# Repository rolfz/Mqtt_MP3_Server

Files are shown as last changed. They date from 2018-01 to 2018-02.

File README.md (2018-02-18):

# Mqtt MP3 Player based on Wemos-D1 ESP8266 circuit and VS1053 audio module

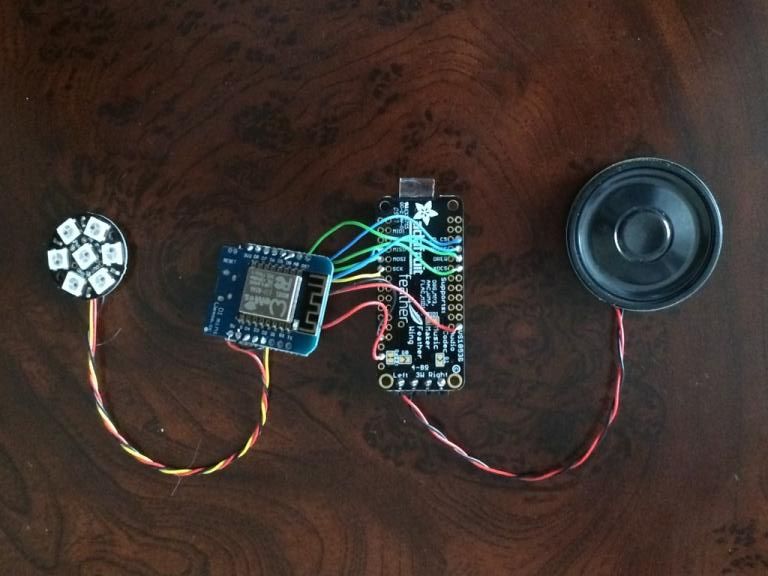
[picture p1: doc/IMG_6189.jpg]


## Functionality:

	This module was created to be controlled by Node-Red over a MQTT Broker.
	The module understands various tags such as:
			 /Zaudio/play  "file to play with extension" 8.3 format
			 /Zaudio/volume xxx (volume in db) 0 to 100db is possible
			 /Zaudio/command stop (will stop the file played)
			
	The module also allows to connect a Neoled display module with 7 leds
			 /Zaudio/neoled #xxyyzz  (set color in hex rgb format

## Hardware:
	Wemos D1 module, SPI bus used to communicate with audio module
	
	Adafruit VS1053 module with 3W amplifier PRODUCT ID: 3436
	
	Micro SD card 128mB our larger FAT format.
	
	Connections:
			Wemos D1		-      VS1053   -   Neoled
			D8						MISO
			D7						MOSI
			D5						SCK
			D4						SD-CS
			D6						MP3-CS
			D3						DREQ
			DO						XDCS
			D2									IN
			+5V						AUDIO +5V	5V
			+3V						DIGIT.+3V
	
	! Use min. 5V 2Amp USB to supply both circuits + LED's
		
## Software Libraries:

	Adafruit_Neopixel
	Adafruit_VS1053_Library-master
	pubsubclient (MQTT library)
	
## Software Main file:
	mqtt_mp3_server.ino contains all customized code based on the MQTT client example
	wifi_settings.h 	contains the WIFI private setting

## Using the Zaudio module with Node-red
	Zaudio was tested with a connection to an MQTT brocker running on a RPI3 board
		Software installed was Openhabian with MQTT and Node-red modules installed.
		
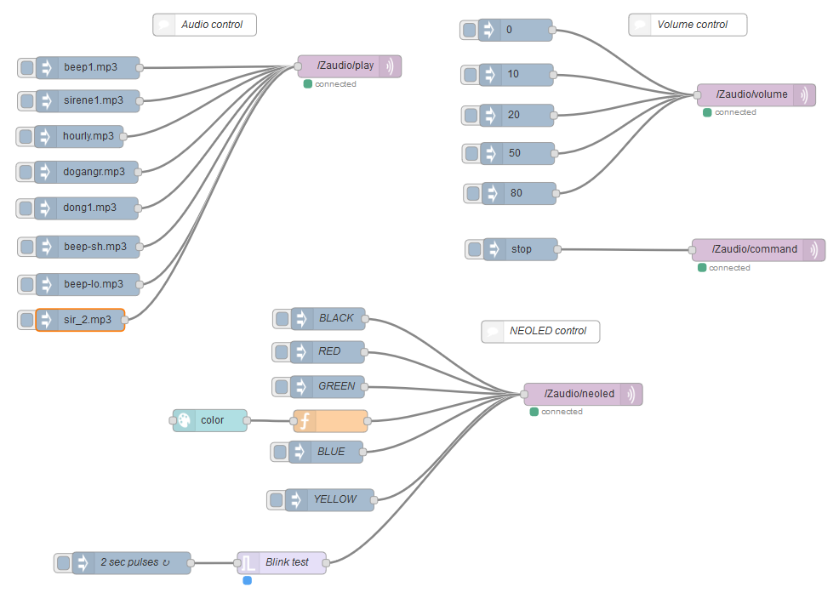
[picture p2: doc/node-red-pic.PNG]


	v1.1 rz 21.2.2018	added OTA code
	v1.0 rz 28.1.2018   orginial code

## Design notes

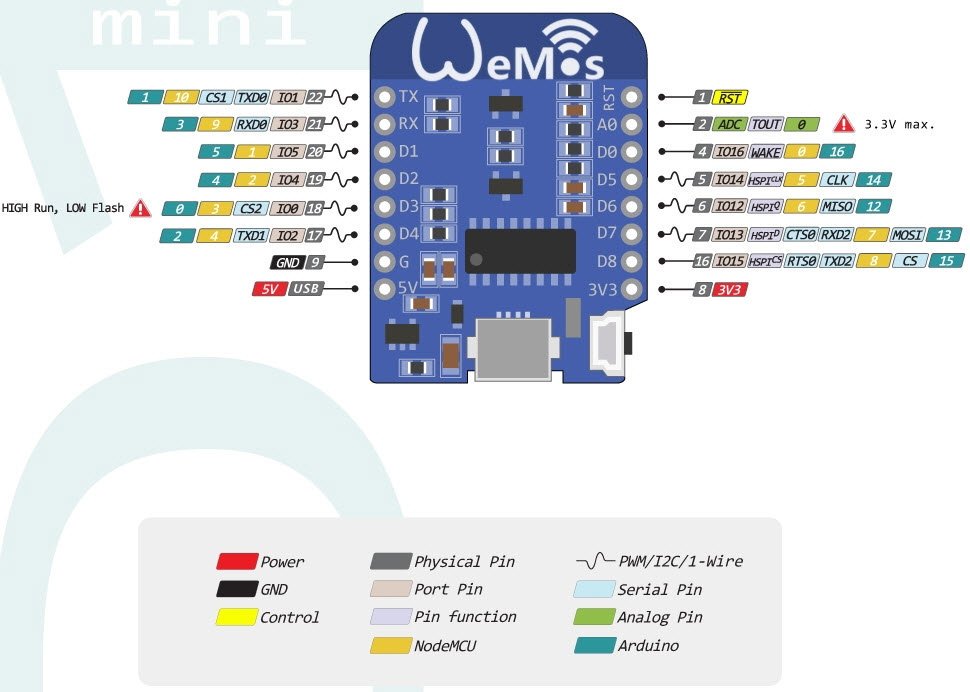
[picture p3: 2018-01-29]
doc/wemos d1 pinout.jpg

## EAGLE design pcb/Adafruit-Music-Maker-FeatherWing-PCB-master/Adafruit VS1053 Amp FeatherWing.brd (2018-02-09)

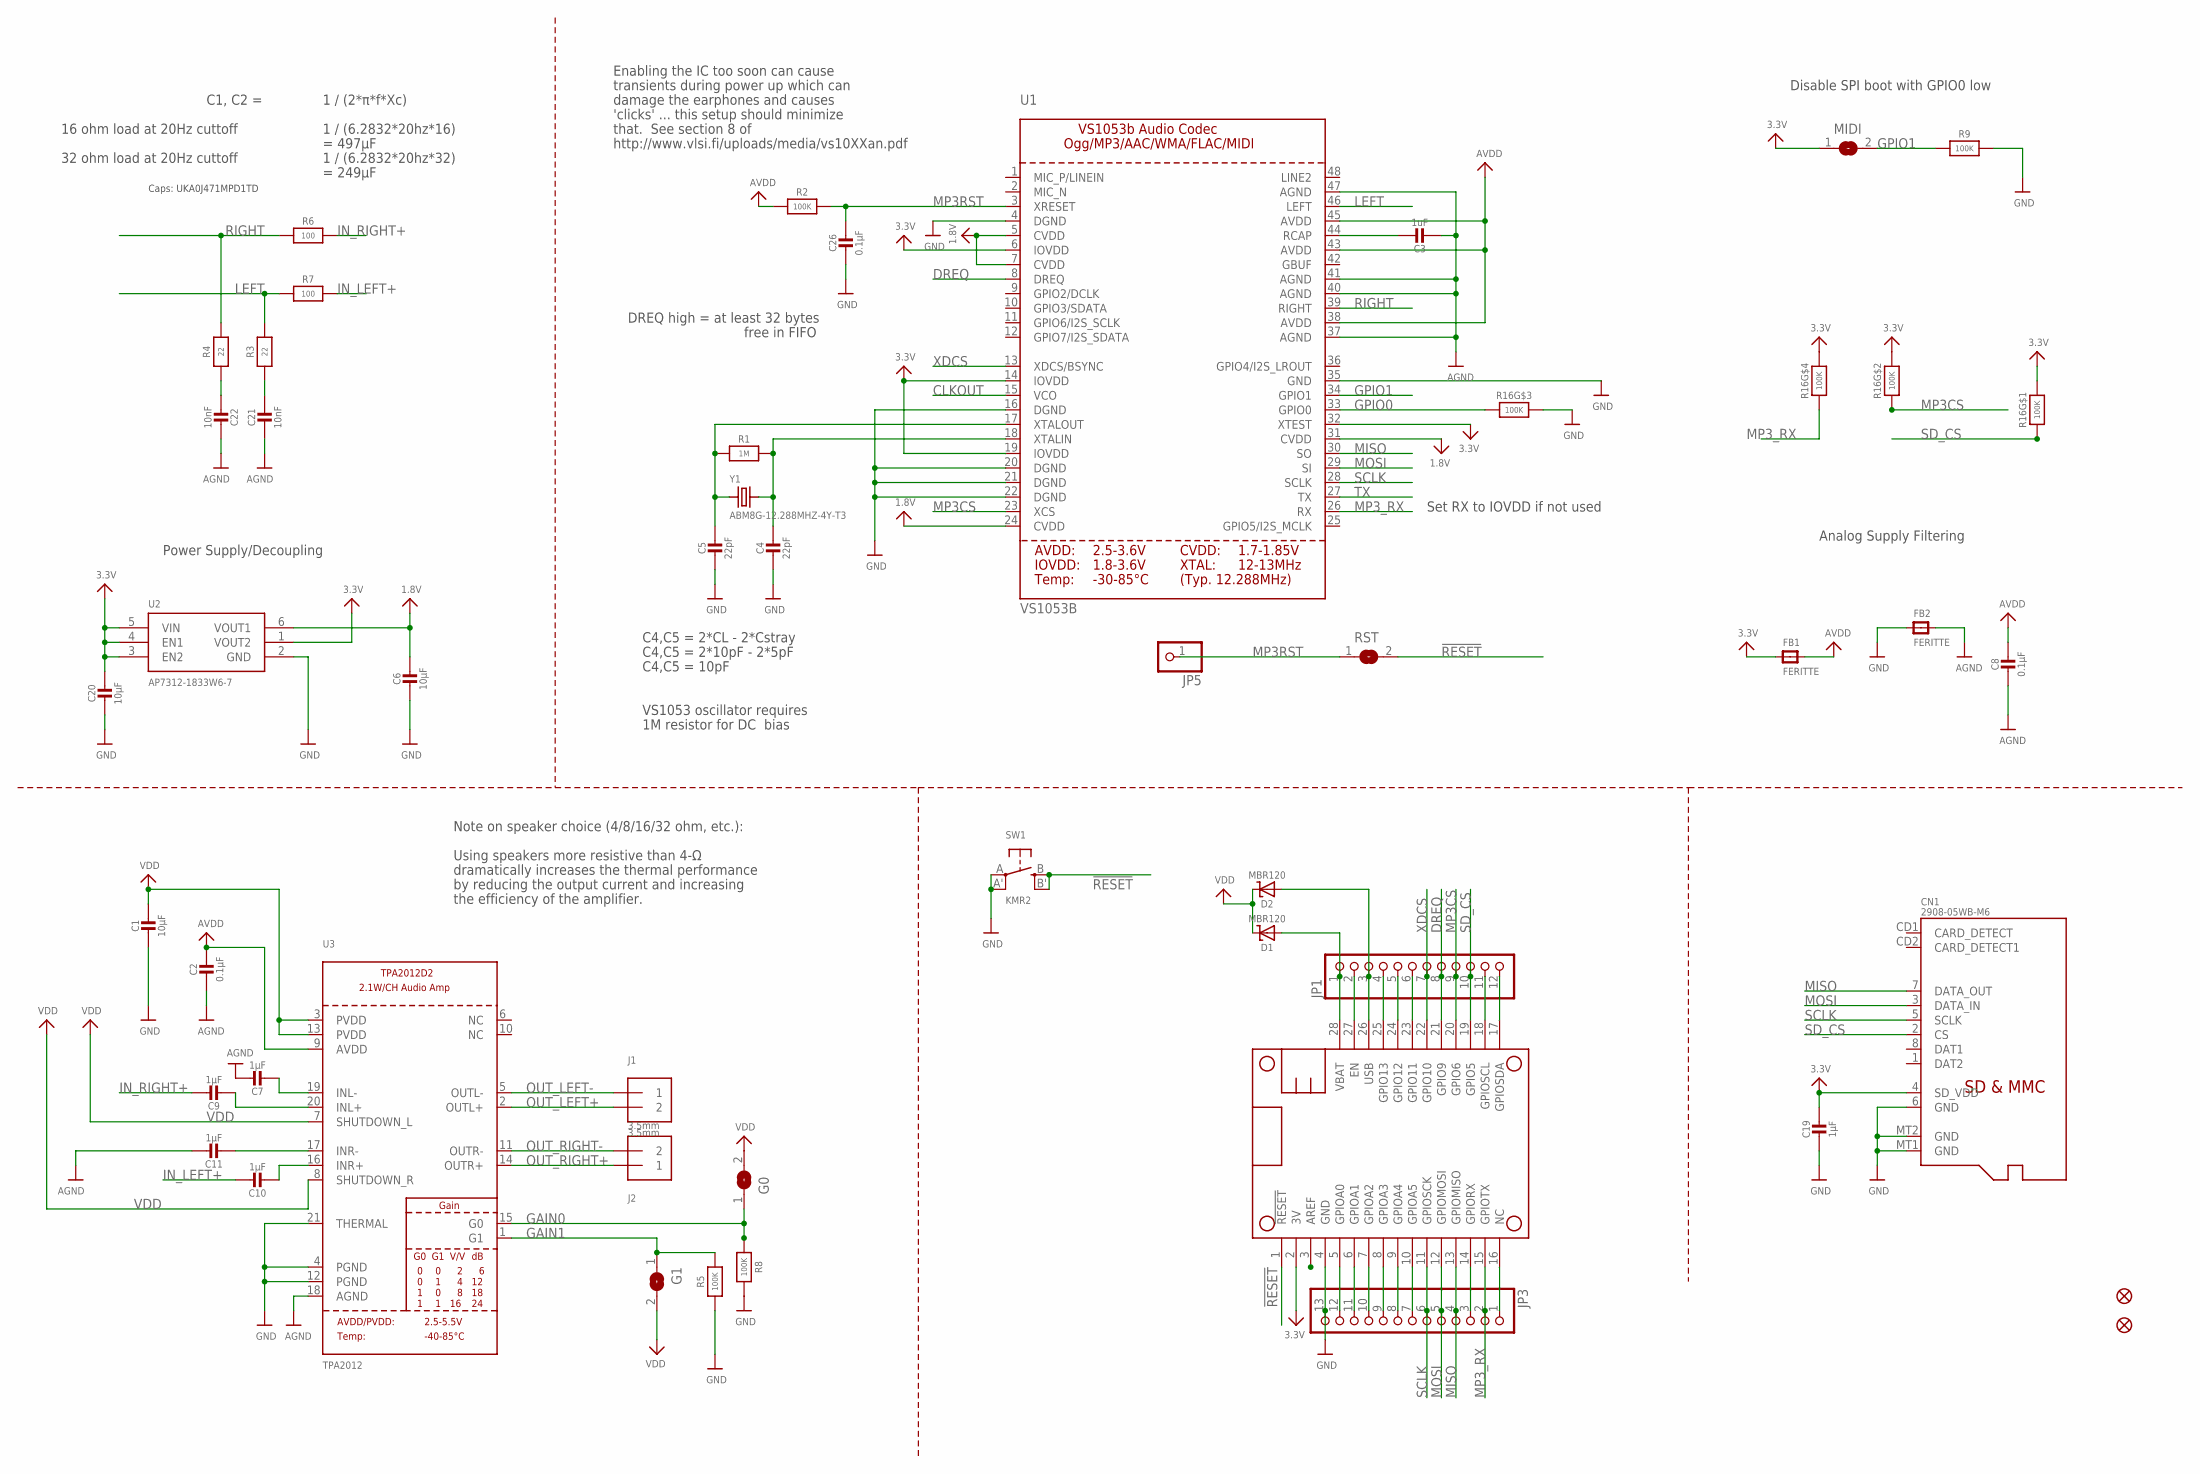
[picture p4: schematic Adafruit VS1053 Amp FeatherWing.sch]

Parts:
C1, C20: 10µF; 0805-NO
C2, C8, C26: 0.1µF; 0603-NO
C3: 1uF; 0603-NO
C4, C5: 22pF; 0603-NO
C6: 10µF; _0805MP
C7, C9, C10, C11, C19: 1µF; 0603-NO
C21, C22: 10nF; 0603-NO
CN1: 2908-05WB-M6; MICROSD
D1, D2: MBR120; SOD-123
FB1, FB2: FERITTE; 0805-NO
FID1, FID2: FIDUCIAL""; FIDUCIAL_1MM
G0, G1: SOLDERJUMPER; SOLDERJUMPER_ARROW_NOPASTE
J1, J2: 3.5mm; TERMBLOCK_1X2-3.5MM
JP1: HEADER-1X12; 1X12_ROUND
JP3: HEADER-1X13; 1X13_ROUND_70
JP5: HEADER-1X1ROUND; 1X01_ROUND
MIDI: SOLDERJUMPER; SOLDERJUMPER_ARROW_NOPASTE
MS1: FEATHERWING_NODIM
R1: 1M; 0603-NO
R2, R5, R8: 100K; 0603-NO
R3, R4: 22; 0603-NO
R6, R7: 100; 0603-NO
R9: 100K; _0603MP
R16: 100K; RESPACK_4X0603
RST: SOLDERJUMPERCLOSED; SOLDERJUMPER_CLOSEDWIRE
SW1: KMR2; BTN_KMR2_4.6X2.8
U1: VS1053B; LQFP48
U2: AP7312-1833W6-7; SOT23-6
U3: TPA2012; WQFN20
Y1: ABM8G-12.288MHZ-4Y-T3; CRYSTAL_3.2X2.5

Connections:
1.8V: C6.1, U1.5 (CVDD), U1.7 (CVDD), U1.24 (CVDD), U1.31 (CVDD), U2.6 (VOUT1)
3.3V: C19.1, C20.1, CN1.4 (SD_VDD), FB1.1, MIDI.1, MS1.2 (3V), R16.5 (2), R16.7 (2), R16.8 (2), U1.6 (IOVDD), U1.14 (IOVDD), U1.19 (IOVDD), U1.32 (XTEST), U2.1 (VOUT2), U2.3 (EN2), U2.4 (EN1), U2.5 (VIN)
!RESET: MS1.1 (!RESET), RST.2, SW1.B (S), SW1.B' (S1)
A: JP3.12, MS1.5 (GPIOA0)
AGND: C2.2, C3.2, C7.1, C8.2, C11.1, C21.2, C22.2, FB2.2, U1.37 (AGND), U1.40 (AGND), U1.41 (AGND), U1.47 (AGND), U3.18 (AGND)
AREF: MS1.3 (AREF)
AVDD: C2.1, C8.1, FB1.2, R2.1, U1.38 (AVDD), U1.43 (AVDD), U1.45 (AVDD), U3.9 (AVDD)
B: JP3.11, MS1.6 (GPIOA1)
C: JP3.10, MS1.7 (GPIOA2)
CLKOUT: U1.15 (VCO)
D: JP3.9, MS1.8 (GPIOA3)
DREQ: JP1.8, MS1.21 (GPIO9), U1.8 (DREQ)
E: JP3.8, MS1.9 (GPIOA4)
EN: JP1.2, MS1.27 (EN)
F: JP3.7, MS1.10 (GPIOA5)
G: JP3.1, MS1.16 (NC)
GAIN0: G0.1, R8.1, U3.15 (G0)
GAIN1: G1.1, R5.2, U3.1 (G1)
GND: C1.2, C4.2, C5.2, C6.2, C19.2, C20.2, C26.2, CN1.6 (GND), CN1.MT1 (GND), CN1.MT2 (GND), FB2.1, JP3.13, MS1.4 (GND), R5.1, R8.2, R9.2, R16.6 (2), SW1.A, SW1.A' (P1), U1.4 (DGND), U1.16 (DGND), U1.20 (DGND), U1.21 (DGND), U1.22 (DGND), U1.35 (GND), U2.2 (GND), U3.4 (PGND), U3.12 (PGND), U3.21 (THERMAL)
GPIO0: R16.3 (1), U1.33 (GPIO0)
GPIO1: MIDI.2, R9.1, U1.34 (GPIO1)
IN_LEFT+: C10.1, R7.1
IN_RIGHT+: C9.1, R6.1
L: JP1.6, MS1.23 (GPIO11)
LEFT: R3.1, R7.2, U1.46 (LEFT)
M: JP1.5, MS1.24 (GPIO12)
MISO: CN1.7 (DATA_OUT), JP3.4, MS1.13 (GPIOMISO), U1.30 (SO)
MOSI: CN1.3 (DATA_IN), JP3.5, MS1.12 (GPIOMOSI), U1.29 (SI)
MP3CS: JP1.9, MS1.20 (GPIO6), R16.2 (1), U1.23 (XCS)
MP3RST: C26.1, JP5.1, R2.2, RST.1, U1.3 (XRESET)
MP3_RX: JP3.2, MS1.15 (GPIOTX), R16.4 (1), U1.26 (RX)
N: JP1.4, MS1.25 (GPIO13)
unnamed: C5.1, R1.1, U1.17 (XTALOUT), Y1.1
unnamed: C4.1, R1.2, U1.18 (XTALIN), Y1.2
unnamed: C3.1, U1.44 (RCAP)
unnamed: C21.1, R3.2
unnamed: C22.1, R4.2
unnamed: C9.2, U3.20 (INL+)
unnamed: C7.2, U3.19 (INL-)
unnamed: C11.2, U3.17 (INR-)
unnamed: C10.2, U3.16 (INR+)
OUT_LEFT+: J1.2, U3.2 (OUTL+)
OUT_LEFT-: J1.1, U3.5 (OUTL-)
OUT_RIGHT+: J2.1, U3.14 (OUTR+)
OUT_RIGHT-: J2.2, U3.11 (OUTR-)
RIGHT: R4.1, R6.2, U1.39 (RIGHT)
SCL: JP1.11, MS1.18 (GPIOSCL)
SCLK: CN1.5 (SCLK), JP3.6, MS1.11 (GPIOSCK), U1.28 (SCLK)
SDA: JP1.12, MS1.17 (GPIOSDA)
SD_CS: CN1.2 (CS), JP1.10, MS1.19 (GPIO5), R16.1
TX: U1.27 (TX)
UART_RX: JP3.3, MS1.14 (GPIORX)
USB: D2.A, JP1.3, MS1.26 (USB)
VBAT: D1.A, JP1.1, MS1.28 (VBAT)
VDD: C1.1, D1.C, D2.C, G0.2, G1.2, U3.3 (PVDD), U3.7 (SHUTDOWN_L), U3.8 (SHUTDOWN_R), U3.13 (PVDD)
XDCS: JP1.7, MS1.22 (GPIO10), U1.13 (XDCS/BSYNC)

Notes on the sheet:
Analog Supply Filtering
C4,C5 = 2*CL - 2*Cstray
C4,C5 = 2*10pF - 2*5pF
C4,C5 = 10pF
VS1053 oscillator requires
1M resistor for DC bias
Set RX to IOVDD if not used
DREQ high = at least 32 bytes
Power Supply/Decoupling
transients during power up which can
damage the earphones and causes
'clicks' ... this setup should minimize
that. See section 8 of
http://www.vlsi.fi/uploads/media/vs10XXan.pdf
Enabling the IC too soon can cause
free in FIFO
Disable SPI boot with GPIO0 low
1 / (2*π*f*Xc)
16 ohm load at 20Hz cuttoff
1 / (6.2832*20hz*16)
C1, C2 =
= 497µF
32 ohm load at 20Hz cuttoff
1 / (6.2832*20hz*32)
= 249µF
Caps: UKA0J471MPD1TD
Using speakers more resistive than 4-Ω
dramatically increases the thermal performance
by reducing the output current and increasing
the efficiency of the amplifier.
Note on speaker choice (4/8/16/32 ohm, etc.):

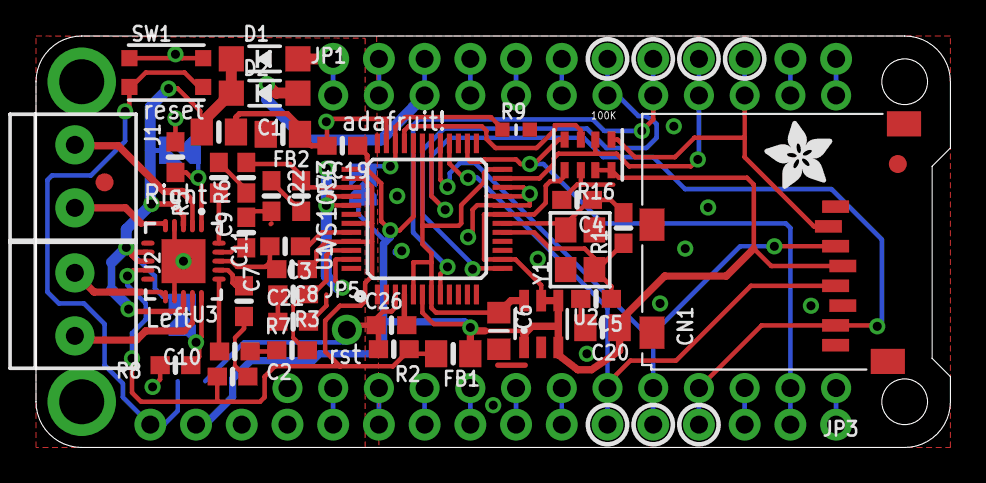
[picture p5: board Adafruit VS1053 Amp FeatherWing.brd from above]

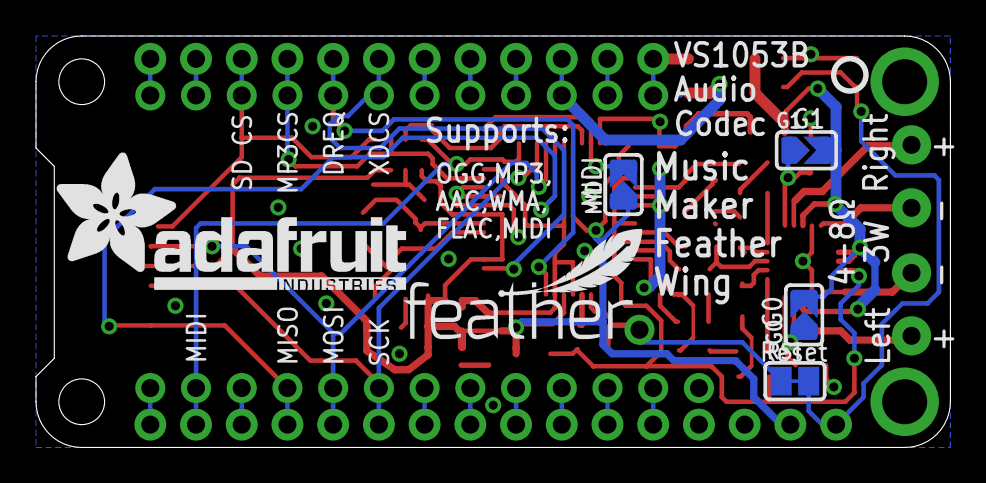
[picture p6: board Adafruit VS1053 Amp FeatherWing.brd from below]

Board: 2 copper layers, 50.8 x 22.9 mm, 52 parts (7 on the bottom side), 53 nets.

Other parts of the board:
U$36: ADAFRUIT_3.5MM
U$37: FEATHERLOGO_SMALL
U$43: PCBFEAT-REV-040
U$55: ADAFRUIT_TEXT_20MM

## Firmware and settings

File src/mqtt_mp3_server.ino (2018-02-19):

// Specifically for use with the Adafruit Feather, the pins are pre-set here!
/* commands:
 *  s: start/stop
 *  p: pause/resume
 */

// include SPI, MP3 and SD libraries
#include <SPI.h>
#include <SD.h>
#include <Adafruit_VS1053.h>
// mqtt related libraries

#include <ESP8266WiFi.h>
#include <PubSubClient.h>
#include <Adafruit_NeoPixel.h>
#include <ArduinoOTA.h>

#include "wifi_settings.h"
const int mqttPort = 1883;
const char* mqttUser = "YourMqttUser";
const char* mqttPassword = "YourMqttUserPassword";

// variables to store mqtt instructions
char playfile[15]; // file to play (deleted when done)
char volume[5];   // audio volume for vs1053
char command[10];
char color[10]; // neoled color
const int delayval = 50; // delay for half a second

//#define ESP8266

// ---------------- VS1053 audio definitions -----------------------------------
// These are the pins used
#define VS1053_RESET   -1     // VS1053 reset pin (not used!)

// Feather ESP8266
#if defined(ESP8266)
  #define VS1053_CS      15 //16     // VS1053 chip select pin (output)
  #define VS1053_DCS     16 //15     // VS1053 Data/command select pin (output)
  #define CARDCS          2     // Card chip select pin
  #define VS1053_DREQ     0     // VS1053 Data request, ideally an Interrupt pin

// Feather ESP32
#elif defined(ESP32)
  #define VS1053_CS      32     // VS1053 chip select pin (output)
  #define VS1053_DCS     33     // VS1053 Data/command select pin (output)
  #define CARDCS         14     // Card chip select pin
  #define VS1053_DREQ    15     // VS1053 Data request, ideally an Interrupt pin

#endif

Adafruit_VS1053_FilePlayer musicPlayer =
  Adafruit_VS1053_FilePlayer(VS1053_RESET, VS1053_CS, VS1053_DCS, VS1053_DREQ, CARDCS);

//------------------- MQTT client definitions ----------------------------------
 WiFiClient espClient;
 PubSubClient mqttClient(espClient);

//------------------ Neopixels LED definitions ---------------------------------
#define PIN            4
// How many NeoPixels are attached to the Arduino?
#define NUMPIXELS      7

Adafruit_NeoPixel pixels = Adafruit_NeoPixel(NUMPIXELS, PIN, NEO_RGB + NEO_KHZ800);

/************************* SETUP *********************************************/
void setup() {
  Serial.begin(115200);

  delay(2000);
  
  pixels.begin(); // This initializes the NeoPixel library.

// connect to wifi network and mqtt server
  WiFi.begin(ssid, password);

  while (WiFi.status() != WL_CONNECTED) {
    delay(500);
    Serial.println("Connecting to WiFi..");
  }
  Serial.println("Connected to the WiFi network");
 
//   WiFi.softAP(ssid,password);             // Start the access point
//  WiFi.softAP(ssid);             // Start the access point

  Serial.print("Access Point \"");
  //Serial.print(ssid);
  Serial.print(ssid);
  Serial.println("\" started\r\n");
  IPAddress myIP = WiFi.softAPIP();
  Serial.print("AP IP address: ");
  Serial.println(myIP);

  startOTA();

  mqttClient.setServer(mqttServer, mqttPort);
  mqttClient.setCallback(callback);

  while (!mqttClient.connected()) {
    Serial.println("Connecting to MQTT...");

//    if (client.connect("ESP8266Client", mqttUser, mqttPassword )) {
    if (mqttClient.connect("ESP8266Client")) {

      Serial.println("connected");

    } else {

      Serial.print("failed with state ");
      Serial.print(mqttClient.state());
      delay(2000);

    }
 }

 mqttClient.publish("/Zaudio", "Hello from MQTT MP3 Servre");
 mqttClient.subscribe("/Zaudio/play"); // we need the audio file name
 mqttClient.subscribe("/Zaudio/volume"); // for volume changes
 mqttClient.subscribe("/Zaudio/command"); // to get the stop command
 mqttClient.subscribe("/Zaudio/neoled"); // to get the stop command
  // if you're using Bluefruit or LoRa/RFM Feather, disable the BLE interface
  //pinMode(8, INPUT_PULLUP);

  // Wait for serial port to be opened, remove this line for 'standalone' operation
  while (!Serial) { delay(1); }

  Serial.println("\n\nZ-Control MQTT VS1053 based audio player V1.1");

  if (! musicPlayer.begin()) { // initialise the music player
     Serial.println(F("Couldn't find VS1053, do you have the right pins defined?"));
     while (1);
  }

  Serial.println(F("VS1053 found"));

  musicPlayer.sineTest(0x44, 500);    // Make a tone to indicate VS1053 is working

  if (!SD.begin(CARDCS)) {
    Serial.println(F("SD failed, or not present"));
    while (1);  // don't do anything more
  }
  Serial.println("SD OK!");

  // list files
  printDirectory(SD.open("/"), 0);

  // Set volume for left, right channels. lower numbers == louder volume!
  musicPlayer.setVolume(100,10);

#if defined(__AVR_ATmega32U4__)
  // Timer interrupts are not suggested, better to use DREQ interrupt!
  // but we don't have them on the 32u4 feather...
  musicPlayer.useInterrupt(VS1053_FILEPLAYER_TIMER0_INT); // timer int
#elif defined(ESP32)
  // no IRQ! doesn't work yet :/
#else
  // If DREQ is on an interrupt pin we can do background
  // audio playing
  musicPlayer.useInterrupt(VS1053_FILEPLAYER_PIN_INT);  // DREQ int
#endif

// Play a file in the background, REQUIRES interrupts!
//  Serial.println(F("Playing ready.mp3"));
//  musicPlayer.startPlayingFile("ready.mp3");
for(int i=0;i<NUMPIXELS;i++){

  // pixels.Color takes RGB values, from 0,0,0 up to 255,255,255
  pixels.setPixelColor(i, pixels.Color(20,0,0)); // Moderately bright green color.
  pixels.show(); // This sends the updated pixel color to the hardware.
//  delay(delayval); // Delay for a period of time (in milliseconds).
  }
// make sure no sound is remaining on boot

  delay(1000);

  mqttClient.publish("/audio/command","stop");

  Serial.println("Mqtt player init done");
} // end of setup

/*********************** CALLBACK *********************************************/
void callback(char* topic, byte* payload, unsigned int length) {

  int i;
//  Serial.print("Message arrived in topic: ");
//  Serial.println(topic);

//------------ decode audio file --------------
  if(strcmp(topic,"/Zaudio/play")==0) {

  Serial.print("Audio: ");
  for (i = 0; i < length; i++) {
         playfile[i] = payload[i];
      }
         playfile[i] = '\0';

    Serial.println(playfile);
    }

//------------decode volume---------------
  if(strcmp(topic,"/Zaudio/volume")==0){

  Serial.print("Volume: ");
  for (i = 0; i < length; i++) {
      volume[i] = payload[i];
    }
      volume[i] = '\0';

      Serial.println(volume);

      musicPlayer.setVolume(atoi(volume),atoi(volume));
  }

//-------------decode command -----------
  if(strcmp(topic,"/Zaudio/command")==0){

  Serial.print("command: ");
  for (i = 0; i < length; i++) {
      command[i] = payload[i];
    }
      command[i] = '\0';

      Serial.println(command);
      if(strcmp(command,"stop")==0)
          musicPlayer.stopPlaying();
  }
  // we could add other commands here

  //-------------decode led color -----------
    if(strcmp(topic,"/Zaudio/neoled")==0){

    Serial.print("color: ");
    for (i = 0; i < length; i++) {
        color[i] = payload[i];
      }
        color[i] = '\0';
        Serial.println(color);

        setColor(color);
    }
} // end callback

/************************** MAIN LOOP *****************************************/
void loop() {
  
  static int lock=0; // lock the message at end of playing to avoid multiple messages

  ArduinoOTA.handle();         // listen for OTA events

  mqttClient.loop();          // run MQTT service


//  Serial.println(lock);

  // File is playing in the background
    if (musicPlayer.stopped() && lock==0) {
    Serial.println("done");
    mqttClient.publish("/Zaudio/state", "done");
    lock=1; // we block new messages
    }

  if( playfile[0] != '\0' && lock==1){
      mqttClient.publish("/Zaudio/state", "playing");
      lock=0;
      //musicPlayer.stopPlaying();
      musicPlayer.startPlayingFile(playfile);
      playfile[0] = '\0';
  }

  // sending commands from the UART interface (USB console)

  if (Serial.available()) {
    char c = Serial.read();

// PRINT HELP ON SERIAL CONSOLE
    if (c == 'h') printHelp();

// PRINT SD CONTENT
    if (c == 'l') {
      Serial.println("\r\n");
      printDirectory(SD.open("/"), 0);
    }

//SEND STOP TO AUDIO Player
    if (c == 's') {
      musicPlayer.stopPlaying();
      Serial.println("Stopped");
    }

// DUMP AUDIO CHIP STATUS
    if(c == 'd'){
      Serial.println("Memory Dump");
      musicPlayer.dumpRegs();
    }

// OTHER AUDIO COMMANDS
    // if we get an 'p' on the serial console, pause/unpause!
    if (c == 'p') {
      if (! musicPlayer.paused()) {
        Serial.println("Paused");
        musicPlayer.pausePlaying(true);
      } else {
        Serial.println("Resumed");
        musicPlayer.pausePlaying(false);
      }
    }

    if(c == '1'){
          Serial.println("playing track001");
            lock=0;
      musicPlayer.startPlayingFile("track001.mp3");
    }
    if(c == '2'){
      Serial.println("playing track002");
     lock=0;
      musicPlayer.startPlayingFile("track002.mp3");
    }
    if(c == '3'){
      Serial.println("playing track003");
      lock=0;
      musicPlayer.startPlayingFile("track003.mp3");
    }
    if(c == '4'){
      Serial.println("playing beep-sh");
      lock=0;
      musicPlayer.startPlayingFile("beep-sh.mp3");
    }
    if(c == '5'){
      Serial.println("playing beep-lo");
      lock=0;
      musicPlayer.startPlayingFile("beep-lo.mp3");
    }
  }
  delay(100);

} // end loop


/********************* PRINT DIRECTORY ***************************************/
/// File listing helper lock=0;
void printDirectory(File dir, int numTabs) {
   while(true) {

     File entry =  dir.openNextFile();
     if (! entry) {
       // no more files
       //Serial.println("**nomorefiles**");
       break;
     }
     for (uint8_t i=0; i<numTabs; i++) {
       Serial.print('\t');
     }
     Serial.print(entry.name());
     if (entry.isDirectory()) {
       Serial.println("/");
       printDirectory(entry, numTabs+1);
     } else {
       // files have sizes, directories do not
       Serial.print("\t\t");
       Serial.println(entry.size(), DEC);
     }
     entry.close();
   }
   Serial.println("\ndone\n");
}

void printHelp(void){
  {
    Serial.println("\r\n");
    Serial.println("Z-Audio MQTT Server");
    Serial.println("===================");
    Serial.println("MP3 audio files on SD card");
    Serial.println("MQTT address /Zaudio/play xxx.mp3");
    Serial.println("Volume /Zaudio/volume 100-0dB");
    Serial.println("Stop /Zaudio/control stop");
    Serial.println("UART commands");
    Serial.println("1,2,3,4,5 play audio files");
    Serial.println("p = pause");
    Serial.println("s = stop");
    Serial.println("l = list SD content");
    Serial.println("d = dump vs1053 status");
    Serial.println("----------------------\r\n");
  }
}

void setColor(char *color){

          int head, r, g, b;

          sscanf(color, "%01s%02x%02x%02x",&head, &r, &g, &b);

          if(color[0]=='#'){
          for(int i=0;i<NUMPIXELS;i++){
              // pixels.Color takes RGB values, from 0,0,0 up to 255,255,255
          pixels.setPixelColor(i, pixels.Color(g,r,b)); // Moderately bright green color.
          pixels.show(); // This sends the updated pixel color to the hardware.
        //  delay(delayval); // Delay for a period of time (in milliseconds).
        //color[0]='\0';
          }
        }
}


void startOTA() { // Start the OTA service
  // Port defaults to 8266
  //ArduinoOTA.setPort(8081);
  ArduinoOTA.setPort(8266);

  ArduinoOTA.setHostname(OTAName);
  ArduinoOTA.setPassword(OTAPassword);

  ArduinoOTA.onStart([]() {
    Serial.println("Start");

    // ADD INIT LED HERE

  });
  ArduinoOTA.onEnd([]() {
    Serial.println("\r\nEnd");
  });
  ArduinoOTA.onProgress([](unsigned int progress, unsigned int total) {
    Serial.printf("Progress: %u%%\r", (progress / (total / 100)));
  });
  ArduinoOTA.onError([](ota_error_t error) {
    Serial.printf("Error[%u]: ", error);
    if (error == OTA_AUTH_ERROR) Serial.println("Auth Failed");
    else if (error == OTA_BEGIN_ERROR) Serial.println("Begin Failed");
    else if (error == OTA_CONNECT_ERROR) Serial.println("Connect Failed");
    else if (error == OTA_RECEIVE_ERROR) Serial.println("Receive Failed");
    else if (error == OTA_END_ERROR) Serial.println("End Failed");
  });
  ArduinoOTA.begin();
  Serial.println("OTA ready\r\n");
  Serial.println("Ready");
  Serial.print("IP address: ");
  Serial.println(WiFi.localIP());
}
/**************************** END OF CODE *************************************/

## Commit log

2018-01-29 Added Neoled support for 7 LED's in circle, controlled by mqtt /Zaudio/neoled #xxyyzz color message
2018-02-09 first commit, v1.0 mqtt player
    [Adafruit VS1053 Amp FeatherWing.brd, Adafruit VS1053 Amp FeatherWing.sch]
